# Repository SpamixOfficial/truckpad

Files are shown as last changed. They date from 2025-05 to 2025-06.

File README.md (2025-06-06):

# The Truckpad - Ready for Calais /:\

truckpad

Ever been driving your truck in ETS2 and realized that:
1. You have too few buttons for your 6 different types of honks?
2. Using a g29-scroll wheel to switch menu tab is janky?

Well oh boy do I have the solution for you! 

The Truckpad is a macropad specifically designed with these problems in mind. It has 4 switches + a modifier switch, which in total allows for up to 8 macros on the switches alone!

But this isn't enough (of course)...

You also need to be able to change tabs and do easy confirmation when fueling, so of course there's a rotary encoder to solve just that. It is also placed with your hand position in mind, so you don't have to do weird finger stretching to use it!

Last but not least it has an OLED screen where you can display information such as your nearest city in ETS2, or whatever you like really, the sky (and ETS2 modding capabilities ) is your limits!

Configuration is done in VIA, so no need to recompile the firmware!

The whole thing also comes in a small form factor so that's nice :D

**Here's also a list of features, in case you don't feel like reading all that!**

## Features 
- 4 switches + 1 modifier switch (toggle) - up to 8 macros!
- Rotary encoder WITH switch placed in an optimal position for your fingers, makes navigation easy in the ETS2 menu tab
- 128*32px OLED screen, display whatever information you like!
- QMK+VIA easy configuration - never been easier to configure huh?
- Debugging? We got a status LED for that :D

## BOM
- 5x Cherry MX Switches
- 2x SK6812 MINI Leds
- 1x XIAO RP2040
- 5x Blank DSA Keycaps
- 4x M3x16 Bolt
- 4x M3 Heatset
- 1x EC11 rotary encoder with switch
- 1x I2C OLED 128x32px

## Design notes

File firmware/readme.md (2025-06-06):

# truckpad

truckpad

The truckpad is a macropad with ETS2 kept in mind when designing!

* Keyboard Maintainer: [SpamixOfficial](https://github.com/SpamixOfficial)
* Hardware Supported: It has an encoder, OLED display, 4 buttons + a modifier button allowing up to 8 different macros spread across 2 layers!
* Hardware Availability: Check the [github repo](https://github.com/spamixofficial/truckpad) for a BOM and how to build it yourself

__It is recommended that you use the qmk cli to avoid any potential issues__
Make example for this keyboard (after setting up your build environment):

    qmk compile -kb truckpad -km default

Flashing example for this keyboard:

    qmk flash -kb truckpad -km default

See the [build environment setup](https://docs.qmk.fm/#/getting_started_build_tools) and the [make instructions](https://docs.qmk.fm/#/getting_started_make_guide) for more information. Brand new to QMK? Start with our [Complete Newbs Guide](https://docs.qmk.fm/#/newbs).

## Bootloader

* **Physical reset button**: Unscrew the case and click the reset button on the Seeed XIAO board inside!

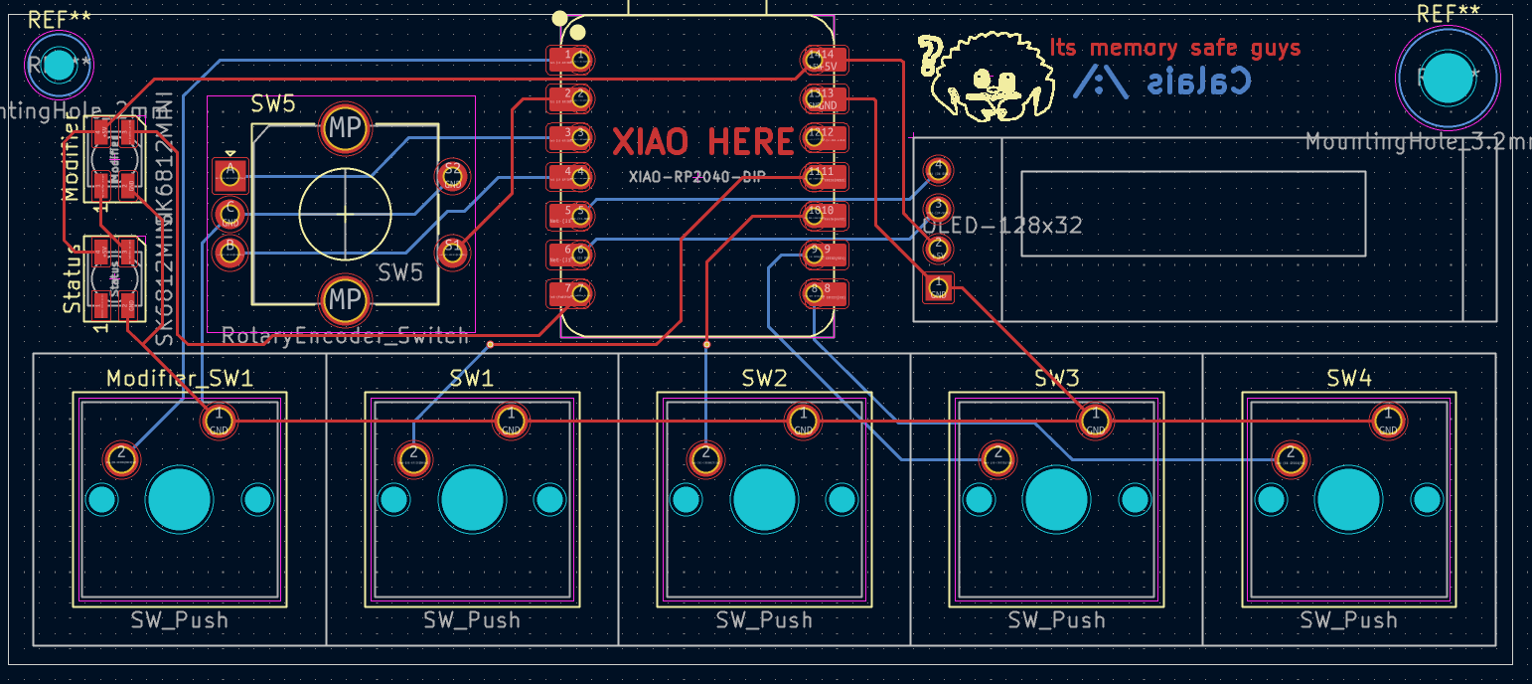
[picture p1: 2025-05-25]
assets/pcb.png

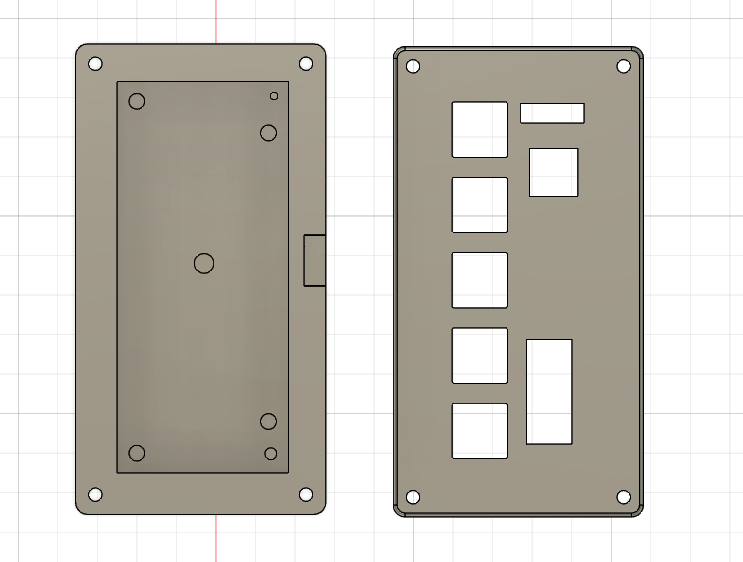
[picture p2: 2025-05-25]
assets/topcase.png

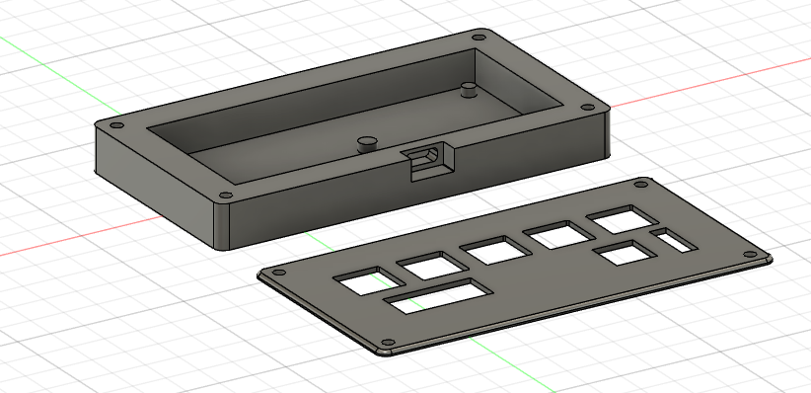
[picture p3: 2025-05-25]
assets/sidecase.png

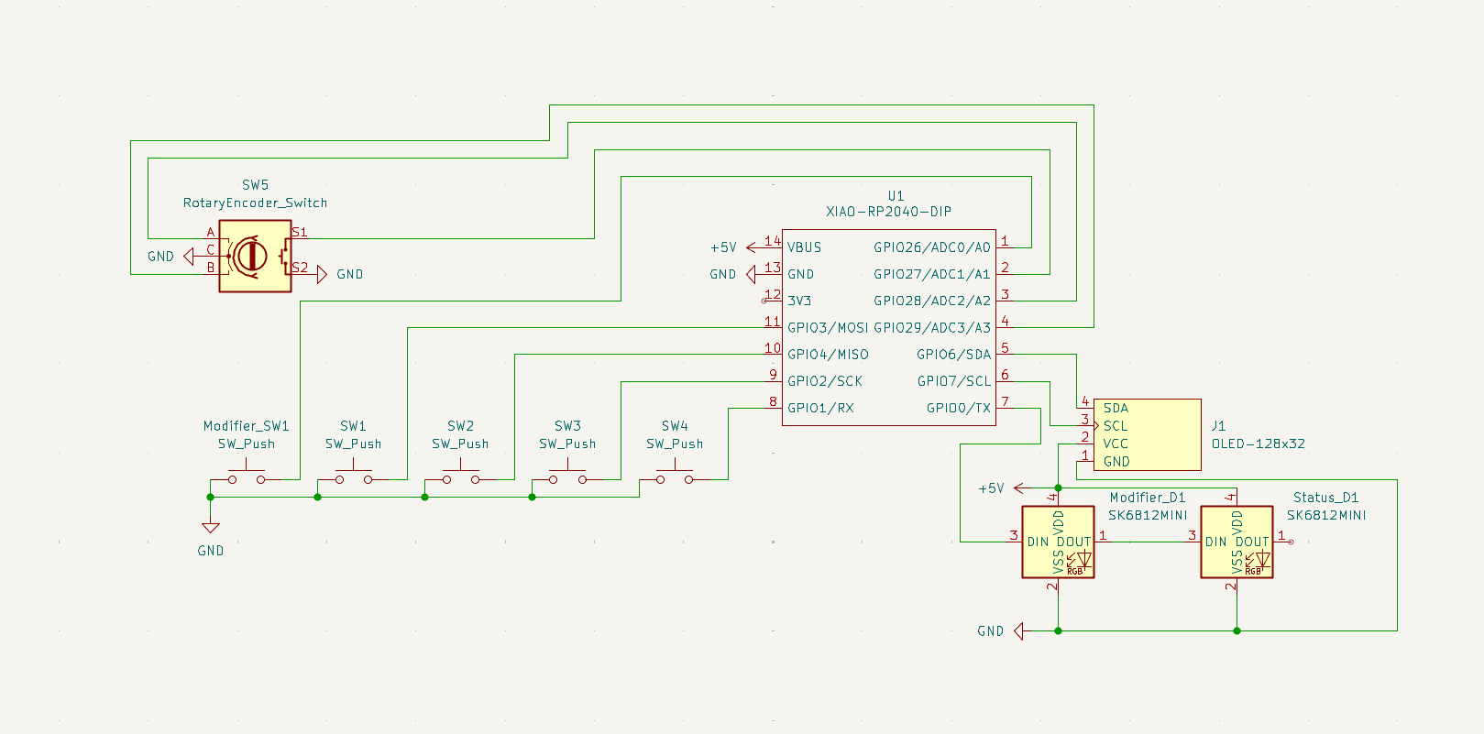
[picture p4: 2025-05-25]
assets/sch.png

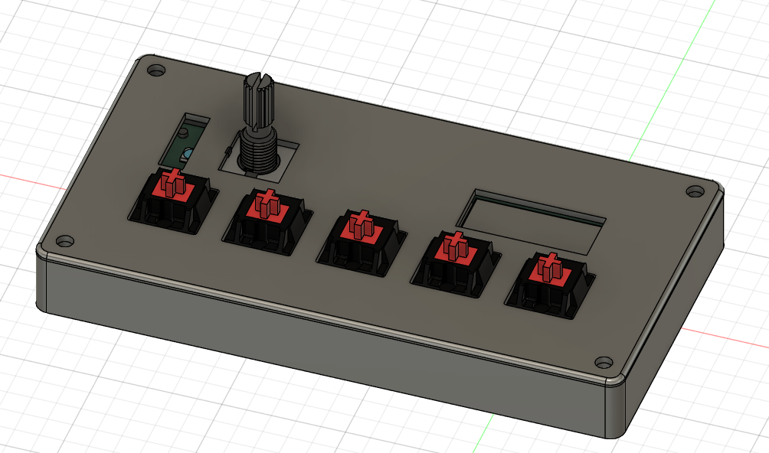
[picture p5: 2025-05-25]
assets/pad.png

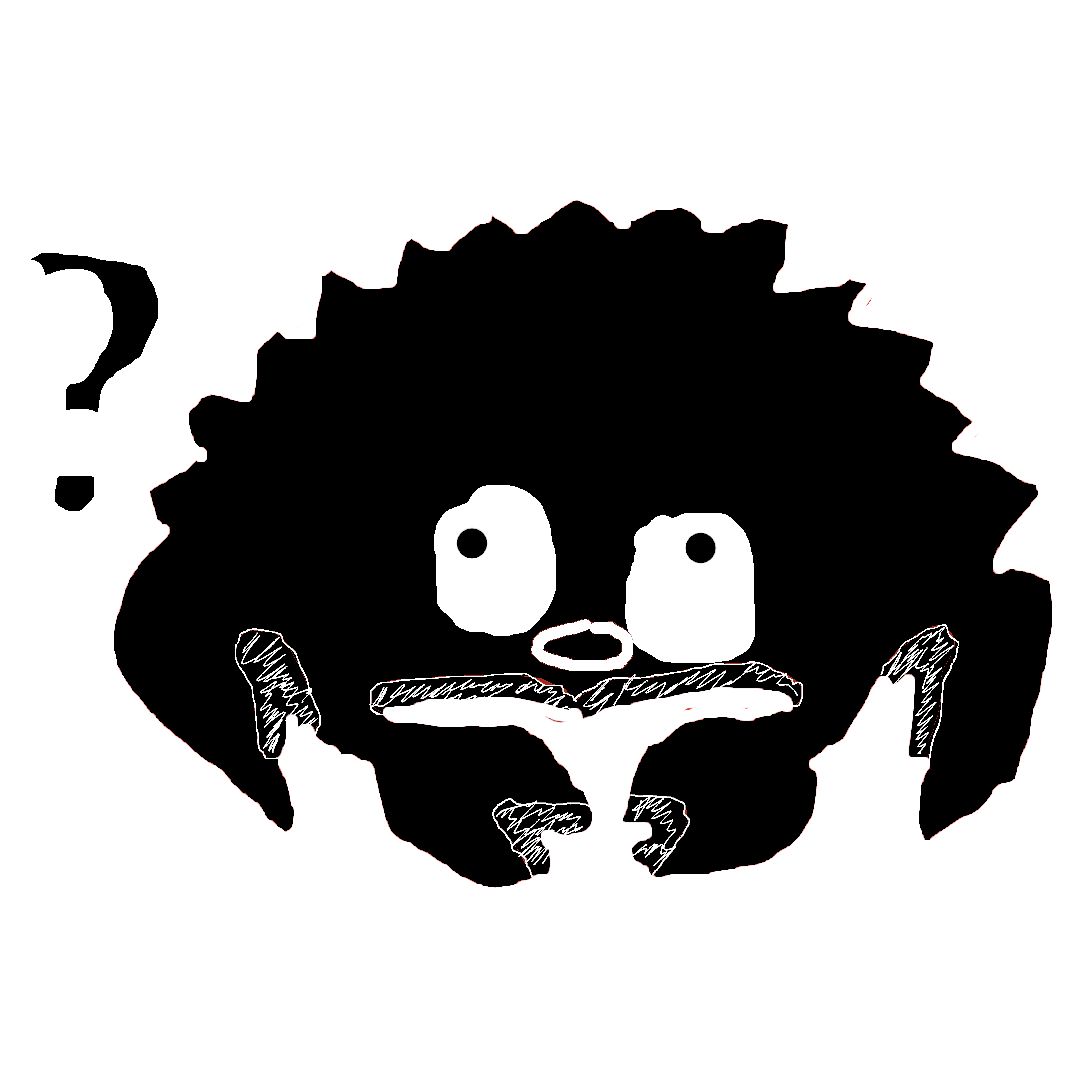
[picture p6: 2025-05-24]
pcb/art/itsmemorysafeguys.png

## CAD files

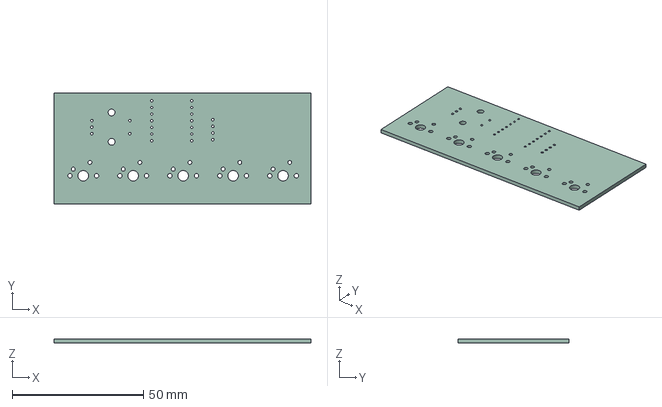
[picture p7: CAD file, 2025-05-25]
pcb/truckpad.step
98.0 x 42.3 x 1.51 mm

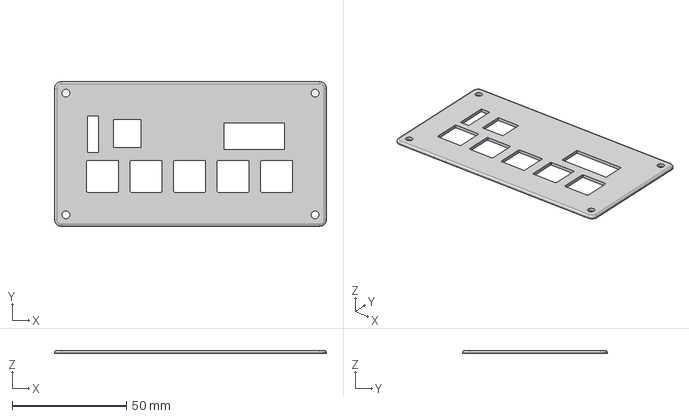
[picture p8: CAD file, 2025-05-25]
production/top.step
119.0 x 63.3 x 1.50 mm

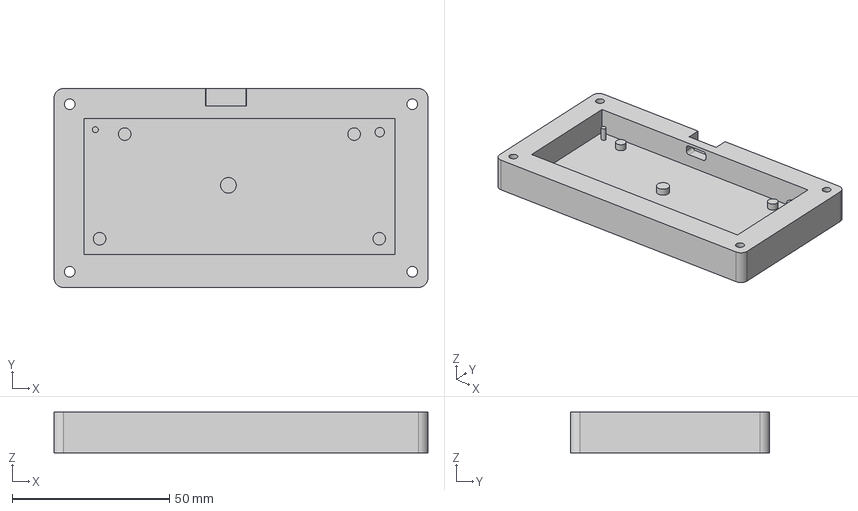
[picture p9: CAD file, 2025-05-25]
production/bottom.step
119.0 x 63.3 x 13.0 mm

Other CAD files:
pcb/truckpad.stl

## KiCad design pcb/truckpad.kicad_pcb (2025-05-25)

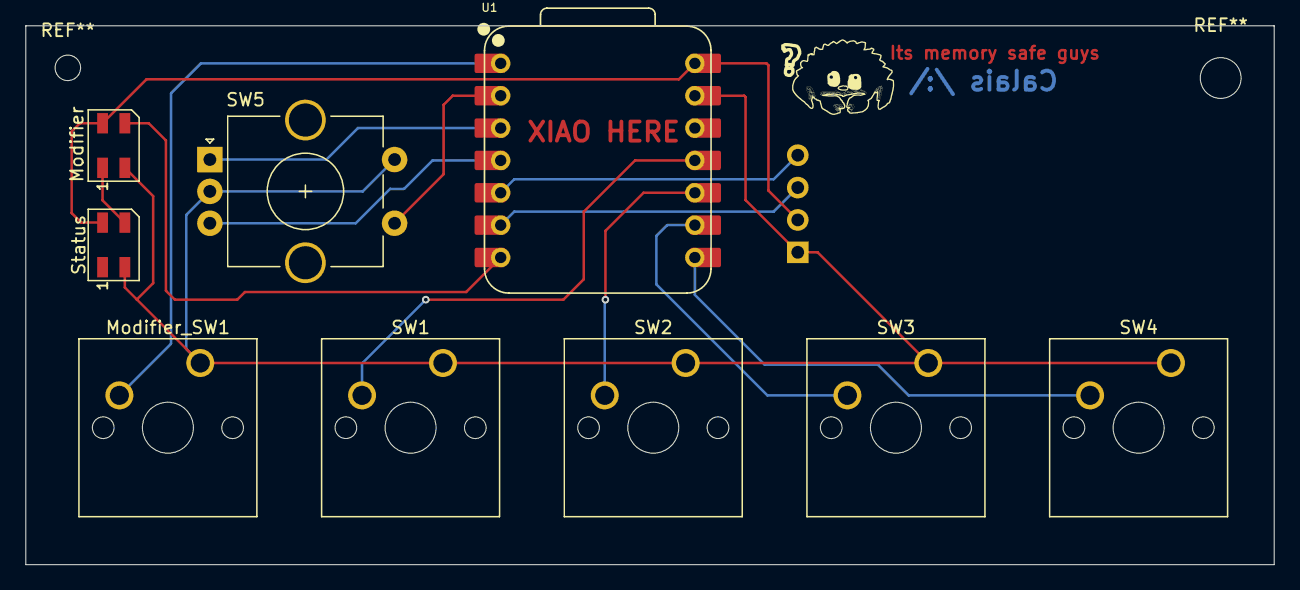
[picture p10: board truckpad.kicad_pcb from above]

Board: 2 copper layers, 98.0 x 42.3 mm, 10 parts (0 on the bottom side), 14 nets.

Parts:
J1: OLED-128x32
Modifier: SK6812MINI; LED_SK6812MINI_PLCC4_3.5x3.5mm_P1.75mm
Modifier_SW1: SW_Push; SW_Cherry_MX_1.00u_PCB
SW1, SW2, SW3, SW4: SW_Push; SW_Cherry_MX_1.00u_PCB
SW5: RotaryEncoder_Switch; RotaryEncoder_Alps_EC11E-Switch_Vertical_H20mm_CircularMoun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
Status: SK6812MINI; LED_SK6812MINI_PLCC4_3.5x3.5mm_P1.75mm
U1: XIAO-RP2040-DIP

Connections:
+5V: J1.2 (VCC), Modifier.4 (VDD), Status.4 (VDD), U1.14 (VBUS)
GND: J1.1 (GND), Modifier.2 (VSS), Modifier_SW1.1, SW1.1, SW2.1, SW3.1, SW4.1, SW5.C, SW5.S2, Status.2 (VSS), U1.13 (GND)
unnamed: J1.3 (SCL), U1.6 (GPIO7/SCL)
unnamed: J1.4 (SDA), U1.5 (GPIO6/SDA)
unnamed: Modifier.3 (DIN), U1.7 (GPIO0/TX)
unnamed: Modifier.1 (DOUT), Status.3 (DIN)
unnamed: SW4.2, U1.8 (GPIO1/RX)
unnamed: SW3.2, U1.9 (GPIO2/SCK)
unnamed: SW1.2, U1.11 (GPIO3/MOSI)
unnamed: SW2.2, U1.10 (GPIO4/MISO)
unnamed: Modifier_SW1.2, U1.1 (GPIO26/ADC0/A0)
unnamed: SW5.S1, U1.2 (GPIO27/ADC1/A1)
unnamed: SW5.A, U1.3 (GPIO28/ADC2/A2)
unnamed: SW5.B, U1.4 (GPIO29/ADC3/A3)

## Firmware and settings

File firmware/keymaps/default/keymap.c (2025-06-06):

// Copyright 2023 QMK
// SPDX-License-Identifier: GPL-2.0-or-later

#include QMK_KEYBOARD_H

enum layers {
    base,
    mod
}layers;

const uint16_t PROGMEM keymaps[][MATRIX_ROWS][MATRIX_COLS] = {
    /*
     * ┌───┬───┬───┬───┬───┬───┐
     * │Enc│M1 │M2 │M3 │M4 │Enc│
     * └───┴───┴───┴───┴───┴───┘
     * Enc: Encoder switch
     * 
     */
    [base] = LAYOUT_def(TG(mod), KC_NO, KC_NO, KC_NO, KC_NO, KC_NO),
    [mod]  = LAYOUT_def(KC_TRNS, KC_NO, KC_NO, KC_NO, KC_NO, KC_NO)
};

#if defined(ENCODER_MAP_ENABLE)
const uint16_t PROGMEM encoder_map[][NUM_ENCODERS][NUM_DIRECTIONS] = {
    [base] = { ENCODER_CCW_CW(KC_NO, KC_NO) },
    [mod] = { ENCODER_CCW_CW(KC_NO, KC_NO) }
};
#endif

#ifdef OLED_ENABLE
bool oled_task_user(void) {
    // Host Keyboard Layer Status
    oled_write_P(PSTR("/:\\"), false);

    if (get_highest_layer(layers) == mod) {
        oled_write_P(PSTR("MOD :D\n"), false);
    };

    return false;
}
#endif

// set mod_led status
layer_state_t layer_state_set_user(layer_state_t state) {
    switch (get_highest_layer(layers)) {
        case mod:
            rgblight_setrgb_at(RGB_RED, 0);
            break;
        default:
            rgblight_setrgb_at(RGB_CYAN, 0);
            break;
    }
    return state;
};

// final init stuff
void keyboard_post_init_user(void) {
    // turn on status LED if everything went fine :D
    rgblight_setrgb_at(RGB_GREEN, 1);
}

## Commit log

2025-05-24 Initial commit (pcb done)
    [truckpad.kicad_pcb, truckpad.kicad_sch]
2025-05-25 Organizing, prepping for submission
    [bottom.step, top.step, truckpad.3mf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]
